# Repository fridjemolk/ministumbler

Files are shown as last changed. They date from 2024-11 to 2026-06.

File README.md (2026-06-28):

# ministumbler, a tiny ESP32 WiFi stumbling tool

This repo contains arduino code, helper python scripts, KiCad and Gerber Files, and hardware information about my ESP32 based WiFi stumbler, designed with low cost, minimal size, and easy of asssembly in mind. It is currently based around the Seeed XIAO/Adafruit QT Py ecosystem.



As of 02/2026, this project exists in 3 different hardware configurations, all of which are based on a GNSS Module, a MicroSD card slot, and a Xiao ESP32-S3:

#### v0.2: A custom PCB backplane supporting each of the modules, plus a [LiPo battery](https://thepihut.com/products/2000mah-3-7v-lipo-battery) charged by the Xiao ESP32-S3's built-in charge circuit, designed to fit into [this case from the Pi Hut](https://thepihut.com/products/small-plastic-project-enclosure-weatherproof-with-clear-top). The KiCad and Gerber files are [available here.](https://github.com/fridjemolk/ministumbler/tree/master/ministumbler_weatherproof_case) 


#### v0.1: A custom flex PCB backplane, supporting each of the modules, designed for stealthy use in the pocket of a bag or inside clothing. The KiCad and Gerber files are [available here.](https://github.com/fridjemolk/ministumbler/tree/master/ministumbler_kicad)


#### v0: A soldered-together stack of all three modules into a very compact rough cube shape. This was the initial prototype and is a little awkward to assemble as it requires deliberately not soldering certain pins for each module. 


All three hardware versions currently [use the same firmware](https://github.com/fridjemolk/ministumbler/blob/master/Ministumbler_WiGLE/Ministumbler_WiGLE.ino), with the same pin configurations, requireing the TX jumper pad to be **CUT** on the SD module and the A1 jumper pad **SOLDERED**. This firmware builds off the firmware created by [lozaning](https://github.com/lozaning) for their [Wifydra Project](https://github.com/lozaning/The_Wifydra), so credit to them for all their hard work in supporting the WiGLE CSV format and handling SD card file creation and management. 

[As of 02/2026, this is the main firmware used for this project](https://github.com/fridjemolk/ministumbler/blob/master/Ministumbler_WiGLE/Ministumbler_WiGLE.ino)

### Required Hardware

#### In the current design version the following three boards are used:

- [Seeed XIAO ESP32S3.](https://wiki.seeedstudio.com/xiao_esp32s3_getting_started/) The S3 variant of the ESP32 has the added benefit of Bluetooth support, and of having a U.FL connector for an external antenna, opening up options for optimising reception. Alternatively, the [Seeed XIAO ESP32C5](https://www.seeedstudio.com/Seeed-Studio-XIAO-ESP32C5-p-6609.html) can be used if 5GHz WiFi support is required, as both boards use the same pinout, however 5GHz is not yet supported by the firmware in this repo.
- [L76K GNSS Module for SeeedStudio XIAO.](https://wiki.seeedstudio.com/get_start_l76k_gnss/) A low-cost, TinyGPS++ compatible GPS module that has proven easy to use and quick to lock. Includes an active GPS antenna, also connected via a U.Fl connector
- [Adafruit microSD Card BFF.](https://learn.adafruit.com/adafruit-microsd-card-bff) A basic microSD card breakout board from adafruit that directly connects an insterted microSD to the SPI pins on the ESP32S3. Since the ESP32S3 has an on-board 3.3v regulator and runs at a 3.3v logic level there is no need for any regulator or level shifter to interface with a microSD card.

The v0 hardware design leads to an issue with the GPS RESET pin being the same as the MOSI (D10) pin of the ESP32, which is used to communicate with the microSD card. For the **v0 configuration ONLY** it is therefore required to ensure that this pin from the ESP32 connects only to the SD board, as the GPS RESET pin is not needed. In fact, the GPS module only requires it's RX, TX, 5V, GND, and 3v3 pins to actually be connected to the ESP32. The 5V pin can also be omitted to disabled the green GPS PPS LED if required.

Optionally, a 3.7V lithium battery can be used to power the device via the BAT +/- pins on the back of the Xiao board, which allow for both powering the Xiao board itself and any devices using it's 3.3v rail (note that no 5v power is available when running on battery), and also for charging the battery over the Xiao's USB-C port - [see this section of the Seeed wiki for more info](https://wiki.seeedstudio.com/xiao_esp32s3_getting_started/#battery-usage). This requires a battery connector being soldered to these pins. In the pictured v0.2 configuration, the pin headers included with the Xiao have been used to solder it to the PCB so as to use the plastic spacer on the headers to allow for the battery wires to reach the BAT +/- pins on the back of the Xiao board. In future this may be updated to use SMD soldering to connect these battery pins to a dedicated battery connector on the board. [This 2000mAh battery](https://thepihut.com/products/2000mah-3-7v-lipo-battery?variant=42143258050755) can power the device for several days in the v0.2 configuration. [This battery connector cable](https://thepihut.com/products/jst-ph-2-pin-cable-male-header-200mm?variant=12364083396670) was used to solder to the Xiao board, and power is applied or removed to the device by simple disconnecting the battery. 

## Software

### This repo, as it currently stands, contains three pieces of software:

- [A fully fledged WiGLE scanning script](https://github.com/fridjemolk/ministumbler/blob/master/Ministumbler_WiGLE/Ministumbler_WiGLE.ino), that scans all wifi channels and creats a WiGLE format CSV that can be uploaded to the WiGLE website.
- [A deprecated, more basic Arduino sketch](https://github.com/fridjemolk/ministumbler/blob/master/GPS_WiFi_XIAO_Serial_CSV/GPS_WiFi_XIAO_Serial_CSV.ino) that interfaces with the GPS module via the ESP32 fork of TinyGPSPlus and uses the Arduino WiFi libray to scan WiFi networks. The sketch will repeatedly generate a line of scanned CSV data with the current GPS location, date, time, and a list of WiFi SSIDs and either output it over USB Serial or save it to a MicroSD card. 
- [A simple python script](https://github.com/fridjemolk/ministumbler/blob/master/csv_write_test.py) that records the data received from the ESP32 over USB Serial and writes it to a CSV file. 

## KiCad Projects

To open these projects in KiCad, clone this repo or download one of the kicad directories and open the `.kicad_pro` file located inside each folder from KiCad's GUI.

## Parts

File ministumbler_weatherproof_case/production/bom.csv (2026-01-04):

Designator | Footprint | Quantity | Value | LCSC Part #
_3 | 54673efd-b35e-49dd-9032-9028876455ca | 1
_2 | 45aaa4f7-1e1c-4795-ac06-623d4f5a70b0 | 1
 |  | 1
ESP32, GPS MODULE, MICRO SD | MOUDLE14P-SMD-2.54-21X17.8MM | 3 | MOUDLE-SEEEDUINO-XIAO-ESP32S3

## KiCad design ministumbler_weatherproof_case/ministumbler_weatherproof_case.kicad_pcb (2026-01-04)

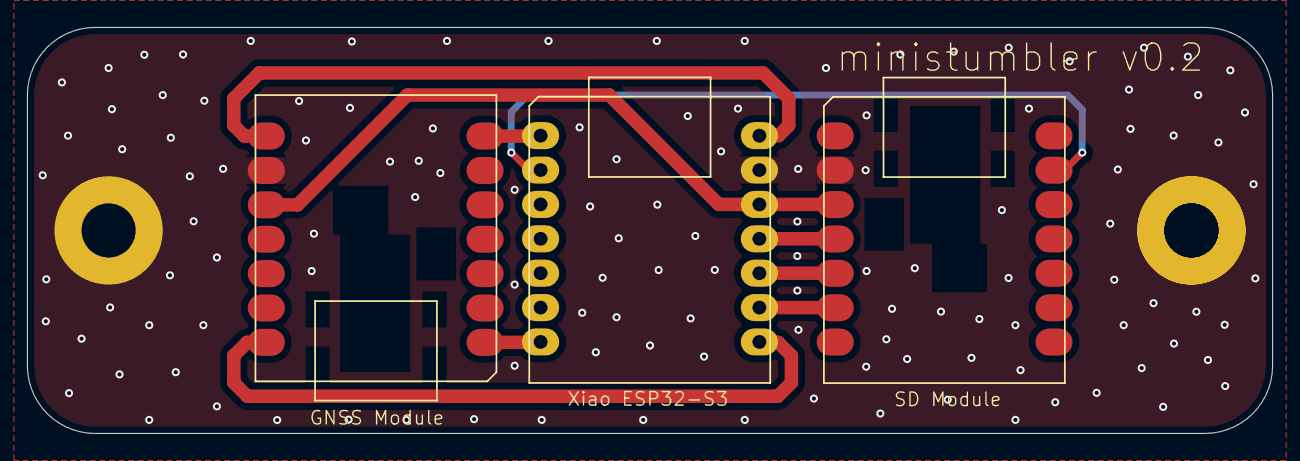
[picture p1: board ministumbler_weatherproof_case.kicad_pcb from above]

Board: 2 copper layers, 92.0 x 30.0 mm, 3 parts (0 on the bottom side), 10 nets.

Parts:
ESP32: MOUDLE-SEEEDUINO-XIAO-ESP32S3; MOUDLE14P-SMD-2.54-21X17.8MM
GPS MODULE: MOUDLE-SEEEDUINO-XIAO-ESP32S3; MOUDLE14P-SMD-2.54-21X17.8MM
MICRO SD: MOUDLE-SEEEDUINO-XIAO-ESP32S3; MOUDLE14P-SMD-2.54-21X17.8MM

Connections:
+3V3: ESP32.12 (3V3), GPS MODULE.10 (PA5_A9_D9_MISO), MICRO SD.3 (PA10_A2_D2)
+5V: ESP32.14 (5V), GPS MODULE.8 (PB09_D7_RX)
GND: ESP32.13 (GND), GPS MODULE.9 (PA7_A8_D8_SCK), MICRO SD.2 (PA4_A1_D1)
GPS_WAKE: ESP32.1 (PA02_A0_D0), GPS MODULE.7 (PB08_A6_TX)
MISO: ESP32.10 (PA5_A9_D9_MISO), MICRO SD.5 (PA8_A4_D4_SDA)
MOSI: ESP32.11 (PA6_A10_D10_MOSI), MICRO SD.4 (PA11_A3_D3)
RX: ESP32.8 (PB09_D7_RX), GPS MODULE.14 (5V)
SCK: ESP32.9 (PA7_A8_D8_SCK), MICRO SD.6 (PA9_A5_D5_SCL)
SD_CS: ESP32.2 (PA4_A1_D1), MICRO SD.13 (GND)
TX: ESP32.7 (PB08_A6_TX), GPS MODULE.1 (PA02_A0_D0)

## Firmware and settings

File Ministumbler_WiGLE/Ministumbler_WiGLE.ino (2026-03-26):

#include <WiFi.h>
#include <SPI.h>
#include <HardwareSerial.h>
#include <TinyGPS++.h>
#include <SD.h>

//TinyGPS++ library documentation is archived here from the developer's now-dead wordpress: https://web.archive.org/web/20250805002451/https://arduiniana.org/libraries/tinygpsplus/
//Quectel L76K GPS Module Protocol Documentation is available here: https://raw.githubusercontent.com/Seeed-Projects/Seeed_L76K-GNSS_for_XIAO/fb74b715224e0ac153c3884e578ee8e024ed8946/docs/Quectel_L76K_GNSS_Protocol_Specification_V1.1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

#define SD_FAT_TYPE 3
#define SD_CS_PIN A1

File csv;
/*
This firmware is inspired by and modified from: 
https://github.com/lozaning/The_Wifydra/blob/main/Dom.ino
https://github.com/lozaning/The_Wifydra/blob/main/Sub.ino

This sketch draws HEAVILY from the above two sources, essentially just modifying them to work as a single script. Credit to https://github.com/lozaning for all of his featured code, modified or unmodified.

https://github.com/dkyazzentwatwa/esp32-gps-wifi-wigle/blob/main/esp32-gps-wifi-wigle.ino
*/
static const int RXPin = D7, TXPin = D6;
static const uint32_t GPSBaud = 9600; // GPS module default baud rate is 9600

//static const bool ENABLE_LED = false;

// The TinyGPSPlus object
TinyGPSPlus gps;

// The serial connection to the GPS device
HardwareSerial GPSSerial(1);

// Counters for WiFi scans and networks found
int scanCount = 0;
int networkCount = 0;
int gpsPrints = 0;


//////////////////////////////////////////////////////////////////////////////////////////////////////////////////////////////
typedef struct struct_message {
  char bssid[64];
  char ssid[32];
  char encryptionType[16];
  int32_t channel;
  int32_t rssi;
} struct_message;

// Constants defined here:
#define LOG_FILE_PREFIX "/gpslog"
#define MAX_LOG_FILES 100
#define LOG_FILE_SUFFIX "csv"
#define LOG_COLUMN_COUNT 11
#define LOG_RATE 500
#define NOTE_DH2 661
const int chipSelect = 10;
File myFile;
char logFileName[13];
int totalNetworks = 0;
unsigned long lastLog = 0;
int integerAltMeters = 0;

//say how many macs we should keep in the buffer to compare for uniqueness
#define mac_history_len 512

const String wigleHeaderFileFormat = "WigleWifi-1.4,appRelease=2.26,model=Ministumbler v0.2,release=0.0.1,device=Ministumbler,display=3fea5e7,board=esp32,brand=Fridje";
char* log_col_names[LOG_COLUMN_COUNT] = {
  "MAC", "SSID", "AuthMode", "FirstSeen", "Channel", "RSSI", "CurrentLatitude", "CurrentLongitude", "AltitudeMeters", "AccuracyMeters", "Type"
};

struct mac_addr {
  unsigned char bytes[6];
};
struct mac_addr mac_history[mac_history_len];
unsigned int mac_history_cursor = 0;

String AP;
String BSSIDchar;
String ENC;
String EncTy;
// Create a struct_message called myData
struct_message myData;

unsigned long lastTime = 0;
unsigned long timerDelay = 200;  // send readings timer

String recentSSID;
String recentSSID1;
String recentSSID2;
//////////////////////////////////////////////////////////////////////////////////////////////////////////////////////////////

void setup()
{
  Serial.begin(115200);
  if(!Serial){
    delay(1);
  } else {
    Serial.println("Serial initialized");
  }
  GPSSerial.begin(GPSBaud, SERIAL_8N1, RXPin, TXPin);
  if(!GPSSerial){
    delay(1);
  } else {
    Serial.println("GPS initialized");
  }
  delay(50);
  Serial.println("Telling L76K which satellite mode to use...");
  Serial.println();
  delay(50);
  GPSSerial.print('$PCAS04,7*1E'); //Tell L76K to use GPS + BeiDou +  GLONASS, which is all the satellite types it supports + QZSS which is always enabled. This will give the best chance at a fix.
  GPSSerial.print('\r\n');
  //Calculate checksum with https://www.meme.au/nmea-checksum.html
  delay(250);
  
  Serial.print("Initializing SD card...");

  if (!SD.begin(SD_CS_PIN)) {
    Serial.println("initialization failed! Check if a card is inserted, and if not, check solder joints on SD module.");
    while(true){
      delay(1);
    }
  } else {
    Serial.print("SD and ");
  }
  Serial.println("GPS initialization done.");

  updateFileName();
  printHeader();

  // initialize digital pin LED_BUILTIN as an output.
  //pinMode(LED_BUILTIN, OUTPUT);
  //digitalWrite(LED_BUILTIN, HIGH);

}

void loop() {
  //Check for GPS lock
  smartDelay(50);
  if (gps.location.isValid() && gps.date.isValid() && gps.time.isValid() && (gps.time.hour() > 0 || gps.time.minute() > 0 || gps.time.second() > 0) && gps.date.year() > 2000){
    print_GPS_date_time();
    scanWiFi();
  } else {
    Serial.println("Waiting for GPS Lock...");
    while (GPSSerial.available())
      gps.encode(GPSSerial.read());
    Serial.print("Current garbage GPS time: ");
    Serial.print(gps.date.year());
    Serial.print(F("-"));
    Serial.print(gps.date.month());
    Serial.print(F("-"));
    Serial.print(gps.date.day());
    Serial.print(F(" "));
    if (gps.time.hour() < 10) Serial.print(F("0"));
    Serial.print(gps.time.hour());
    Serial.print(F(":"));
    if (gps.time.minute() < 10) Serial.print(F("0"));
    Serial.print(gps.time.minute());
    Serial.print(F(":"));
    if (gps.time.second() < 10) Serial.print(F("0"));
    Serial.print(gps.time.second());
    Serial.print(F(":"));
    if (gps.time.centisecond() < 10) Serial.print(F("0"));
    Serial.print(gps.time.centisecond());
    Serial.println(".");
    smartDelay(1000);
  }
}

void print_GPS_date_time(){
    Serial.print("Current GPS time: ");
    Serial.print(gps.date.year());
    Serial.print(F("-"));
    Serial.print(gps.date.month());
    Serial.print(F("-"));
    Serial.print(gps.date.day());
    Serial.print(F(" "));
    if (gps.time.hour() < 10) Serial.print(F("0"));
    Serial.print(gps.time.hour());
    Serial.print(F(":"));
    if (gps.time.minute() < 10) Serial.print(F("0"));
    Serial.print(gps.time.minute());
    Serial.print(F(":"));
    if (gps.time.second() < 10) Serial.print(F("0"));
    Serial.print(gps.time.second());
    Serial.print(F(":"));
    if (gps.time.centisecond() < 10) Serial.print(F("0"));
    Serial.print(gps.time.centisecond());
    Serial.println(".");
}

void scanWiFi(){
  char Buf[50];
  char bufBSSID[64];
  char BufEnc[50];
  if ((millis() - lastTime) > timerDelay) {
    // Set values to send

    //myData.b = random(1,20);
    //myData.c = 1.2;
    //sytanx thus: scanNetworks(bool async, bool show_hidden, bool passive, uint32_t max_ms_per_chan, uint8_t channel)
    int n = WiFi.scanNetworks(false,true,true); //passive scan with hidden networks on all channels and default dwell time
    //int n = WiFi.scanNetworks(); //basic scan, promiscuous 
    if (n == 0) {
      Serial.println("No networks found");
      Serial.println("No networks found");
    } else {
      for (int8_t i = 0; i < n; i++) {
        //delay(10);
        if (seen_mac(WiFi.BSSID(i))) {
          Serial.println("We've already seen it");
          //BSSIDchar = WiFi.BSSID(i);
          //BSSIDchar.toCharArray(bufBSSID, 64);
          //strcpy(myData.bssid, Buf);
          //Serial.println(myData.bssid);
          continue;
        }
        Serial.println("We havent seen it");
        String MacString = WiFi.BSSIDstr(i).c_str();
        //myData.bssid = MacString;
        MacString.toCharArray(bufBSSID, 64);
        strcpy(myData.bssid, bufBSSID);
        Serial.println(myData.bssid);
        //myData.bssid = WiFi.BSSID(i);
        //Serial.print("MyData.bssid: ");

        //Serial.println(myData.bssid);
        String AP = WiFi.SSID(i);
        AP.toCharArray(Buf, 50);
        strcpy(myData.ssid, Buf);
        Serial.print("SSID: ");
        Serial.println(myData.ssid);
        //String ENC = security_int_to_string(WiFi.encryptionType(i));

        //ENC.toCharArray(BufEnc, 32);
        //strcpy(myData.encryptionType, BufEnc);
        //myData.encryptionType = authtype;
        switch (WiFi.encryptionType(i)) {
          case WIFI_AUTH_OPEN:
            EncTy = "Open";
            break;
          case WIFI_AUTH_WEP:
            EncTy = "WEP";
            break;
          case WIFI_AUTH_WPA_PSK:
            EncTy = "WPA PSK";
            break;
          case WIFI_AUTH_WPA2_PSK:
            EncTy = "WPA2 PSK";
            break;
          case WIFI_AUTH_WPA_WPA2_PSK:
            EncTy = "WPA/WPA2 PSK";
            break;
          case WIFI_AUTH_WPA2_ENTERPRISE:
            EncTy = "WPA2 Enterprise";
            break;
          default:
            EncTy = "Unknown";
            break;
        }
        EncTy.toCharArray(BufEnc, 16);
        strcpy(myData.encryptionType, BufEnc);
        Serial.print("Encryption: ");
        Serial.println(myData.encryptionType);

        myData.channel = WiFi.channel(i);
        myData.rssi = WiFi.RSSI(i);
        save_mac(WiFi.BSSID(i));
        writeToCSV((uint8_t*)&myData, sizeof(myData));
        //digitalWrite(2, LOW);
        delay(200);
        //digitalWrite(2, HIGH);
      }
      lastTime = millis();
    }
  }
}

void save_mac(unsigned char* mac) {
  //Save a MAC address into the recently seen array.
  if (mac_history_cursor >= mac_history_len) {
    mac_history_cursor = 0;
  }
  struct mac_addr tmp;
  for (int x = 0; x < 6; x++) {
    tmp.bytes[x] = mac[x];
  }

  mac_history[mac_history_cursor] = tmp;
  mac_history_cursor++;
  Serial.print("Mac len ");
  Serial.println(mac_history_cursor);
}

bool mac_cmp(struct mac_addr addr1, struct mac_addr addr2) {
  //Return true if 2 mac_addr structs are equal.
  for (int y = 0; y < 6; y++) {
    if (addr1.bytes[y] != addr2.bytes[y]) {
      return false;
    }
  }
  return true;
}

bool seen_mac(unsigned char* mac) {
  //Return true if this MAC address is in the recently seen array.

  struct mac_addr tmp;
  for (int x = 0; x < 6; x++) {
    tmp.bytes[x] = mac[x];
  }

  for (int x = 0; x < mac_history_len; x++) {
    if (mac_cmp(tmp, mac_history[x])) {
      return true;
    }
  }
  return false;
}

void print_mac(struct mac_addr mac) {
  //Print a mac_addr struct nicely.
  for (int x = 0; x < 6; x++) {
    Serial.print(mac.bytes[x], HEX);
    Serial.print(":");
  }
}

String security_int_to_string(int security_type) {
  //Provide a security type int from WiFi.encryptionType(i) to convert it to a String which Wigle CSV expects.
  String authtype = "";
  switch (security_type) {
    case WIFI_AUTH_OPEN:
      authtype = "[OPEN]";
      break;

    case WIFI_AUTH_WEP:
      authtype = "[WEP]";
      break;

    case WIFI_AUTH_WPA_PSK:
      authtype = "[WPA_PSK]";
      break;

    case WIFI_AUTH_WPA2_PSK:
      authtype = "[WPA2_PSK]";
      break;

    case WIFI_AUTH_WPA_WPA2_PSK:
      authtype = "[WPA_WPA2_PSK]";
      break;

    case WIFI_AUTH_WPA2_ENTERPRISE:
      authtype = "[WPA2]";
      break;

    //Requires at least v2.0.0 of https://github.com/espressif/arduino-esp32/
    case WIFI_AUTH_WPA3_PSK:
      authtype = "[WPA3_PSK]";
      break;

    case WIFI_AUTH_WPA2_WPA3_PSK:
      authtype = "[WPA2_WPA3_PSK]";

    default:
      authtype = "";
  }

  return authtype;
}

void updateFileName() {
  int i = 0;
  for (; i < MAX_LOG_FILES; i++) {
    memset(logFileName, 0, strlen(logFileName));
    sprintf(logFileName, "%s%d.%s", LOG_FILE_PREFIX, i, LOG_FILE_SUFFIX);
    if (!SD.exists(logFileName)) {
      Serial.println("we picked a new file name");
      Serial.println(logFileName);
      break;
    } else {
      Serial.print(logFileName);
      Serial.println(" exists");
    }
  }
  Serial.println("File name: ");
  Serial.println(logFileName);
}

void printHeader() {
  File logFile = SD.open(logFileName, FILE_WRITE);
  if (logFile) {
    int i = 0;
    logFile.println(wigleHeaderFileFormat);  // comment out to disable Wigle header
    for (; i < LOG_COLUMN_COUNT; i++) {
      logFile.print(log_col_names[i]);
      if (i < LOG_COLUMN_COUNT - 1)
        logFile.print(',');
      else
        logFile.println();
    }
    logFile.close();
  }
}

static void smartDelay(unsigned long ms)  // custom version of delay() ensures that the gps object is being "fed".
{
  unsigned long start = millis();
  do {
    while (GPSSerial.available())
      gps.encode(GPSSerial.read());
  } while (millis() - start < ms);
}

//Function that will be executed when scan is complete
void writeToCSV(const uint8_t* incomingData, int len) {
  File logFile = SD.open(logFileName, FILE_APPEND);
  memcpy(&myData, incomingData, sizeof(myData));
  char buffer[10];
  Serial.print("Bytes received: ");
  Serial.println(len);
  Serial.print("Mac: ");
  Serial.println(myData.bssid);
  logFile.print(myData.bssid);
  logFile.print(",");
  Serial.print("SSID: ");
  Serial.println(myData.ssid);
  String SSIDString = myData.ssid;
  if(SSIDString.indexOf(",") > 0) {
    SSIDString = "\""+SSIDString+"\"";
  }
  logFile.print(SSIDString);
  logFile.print(",");
  Serial.print("Encryption: ");
  Serial.println(myData.encryptionType);
  logFile.print(myData.encryptionType);
  logFile.print(",");
  Serial.print("First seen: ");

  //date
  Serial.println(gps.date.year());
  logFile.print(gps.date.year());
  logFile.print("-");

  snprintf(buffer , sizeof buffer, "%02d", gps.date.month());
  Serial.print(buffer);
  logFile.print(buffer);
  logFile.print("-");

  snprintf(buffer , sizeof buffer, "%02d", gps.date.day());
  Serial.print(buffer);
  logFile.print(buffer);

  logFile.print(" ");

  //time
  snprintf(buffer , sizeof buffer, "%02d", gps.time.hour());
  Serial.print(buffer);
  logFile.print(buffer);
  logFile.print(":");

  snprintf(buffer , sizeof buffer, "%02d", gps.time.minute());
  Serial.print(buffer);
  logFile.print(buffer);
  logFile.print(":");

  snprintf(buffer , sizeof buffer, "%02d", gps.time.second());
  Serial.print(buffer);
  logFile.print(buffer);

  logFile.print(",");
  Serial.print("Channel: ");
  Serial.println(myData.channel);
  logFile.print(myData.channel);
  logFile.print(",");
  Serial.print("RSSI:  ");
  Serial.println(myData.rssi);
  logFile.print(myData.rssi);
  logFile.print(",");
  Serial.print("Lat: ");
  Serial.println(gps.location.lat(), 8);
  logFile.print(gps.location.lat(), 8);
  logFile.print(",");
  Serial.print("Lon: ");
  Serial.println(gps.location.lng(), 8);
  logFile.print(gps.location.lng(), 8);
  logFile.print(",");
  Serial.print("Altitude: ");
  integerAltMeters = int(round(gps.altitude.meters()));
  Serial.println(integerAltMeters);
  logFile.print(integerAltMeters);
  logFile.print(",");
  Serial.print("HDOP: ");
  Serial.println(gps.hdop.value());
  // Convert HDOP to accuracy in meters (HDOP*100 / 10 = rough accuracy)
  logFile.print(gps.hdop.value() / 10.0, 1);
  logFile.print(",");
  Serial.print("BiD: ");
  logFile.print("WIFI");
  logFile.println();
  logFile.close();
  recentSSID2 = recentSSID1;
  recentSSID1 = recentSSID;
  recentSSID = myData.ssid;
  Serial.println();
  totalNetworks +=1;
  Serial.print("Total Networks: ");
  Serial.println(totalNetworks);

  Serial.println();
  Serial.println();
  Serial.println();
}

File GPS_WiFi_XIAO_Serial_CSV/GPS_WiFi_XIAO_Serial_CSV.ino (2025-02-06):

#include <WiFi.h>
//#include <WiFiAP.h>
//#include <WiFiClient.h>
//#include <WiFiGeneric.h>
//#include <WiFiMulti.h>
//#include <WiFiScan.h>
//#include <WiFiServer.h>
//#include <WiFiSTA.h>
//#include <WiFiType.h>
//#include <WiFiUdp.h>
#include <TinyGPSPlus.h>
#include <SoftwareSerial.h>
#include <SPI.h>
#include "SdFat.h"
SdFat SD;

#define SD_FAT_TYPE 3
#define SD_CS_PIN A1

File csv;
/*
Includes some code inspired by and modified from: https://github.com/dkyazzentwatwa/esp32-gps-wifi-wigle/blob/main/esp32-gps-wifi-wigle.ino
*/
static const int RXPin = D7, TXPin = D6;
static const uint32_t GPSBaud = 9600;

// The TinyGPSPlus object
TinyGPSPlus gps;

// The serial connection to the GPS device
SoftwareSerial ss(RXPin, TXPin);

// Counters for WiFi scans and networks found
int scanCount = 0;
int networkCount = 0;
int gpsPrints = 0;

void setup()
{
  Serial.begin(115200);
  ss.begin(GPSBaud);

  Serial.print("Initializing SD card...");

  if (!SD.begin(SD_CS_PIN)) {
    Serial.println("initialization failed!");
    return;
  }
  Serial.println("initialization done.");

  //open the file
  csv = SD.open("ministumbler.csv", FILE_WRITE);

  // initialize digital pin LED_BUILTIN as an output.
  pinMode(LED_BUILTIN, OUTPUT);
  digitalWrite(LED_BUILTIN, LOW);

  //Serial.println(F("DeviceExample.ino"));
  //Serial.println(F("A simple demonstration of TinyGPSPlus with an attached GPS module"));
  //Serial.print(F("Testing TinyGPSPlus library v. ")); Serial.println(TinyGPSPlus::libraryVersion());
  //Serial.println(F("by Mikal Hart"));
  //Serial.println();

  Serial.print("Latitude");
  Serial.print(F(","));
  Serial.print("Longitude");
  Serial.print(F(","));
  Serial.print("Month");
  Serial.print(F(","));
  Serial.print("Day");
  Serial.print(F(","));
  Serial.print("Year");
  Serial.print(F(","));
  Serial.print("Hour");
  Serial.print(F(","));
  Serial.print("Minute");
  Serial.print(F(","));
  Serial.print("Second");
  Serial.print(F(","));
  Serial.print("Centisecond");
  Serial.print(F(","));
  Serial.print("Scan Count");
  Serial.print(F(","));
  Serial.print("Network Count");
  Serial.print(F(","));
  Serial.print("SSID");
  Serial.print(F(","));
  Serial.print("RSSI");
  Serial.print(F(","));
  Serial.print("MAC");
  Serial.print(F(","));
  Serial.println("");

  if(csv){
    csv.print("Latitude");
    csv.print(F(","));
    csv.print("Longitude");
    csv.print(F(","));
    csv.print("Month");
    csv.print(F(","));
    csv.print("Day");
    csv.print(F(","));
    csv.print("Year");
    csv.print(F(","));
    csv.print("Hour");
    csv.print(F(","));
    csv.print("Minute");
    csv.print(F(","));
    csv.print("Second");
    csv.print(F(","));
    csv.print("Centisecond");
    csv.print(F(","));
    csv.print("Scan Count");
    csv.print(F(","));
    csv.print("Network Count");
    csv.print(F(","));
    csv.print("SSID");
    csv.print(F(","));
    csv.print("RSSI");
    csv.print(F(","));
    csv.print("MAC");
    csv.print(F(","));
    csv.println("");
    csv.flush();
  }

}

void loop(){
  // This sketch displays information every time a new sentence is correctly encoded.
  while (ss.available() > 0){
    if (gps.encode(ss.read()) && gps.location.isValid() && gps.date.isValid() && gps.time.isValid()){
      scanWiFiNetworks();
      csv.flush();
      digitalWrite(LED_BUILTIN, HIGH);
    } else {
      digitalWrite(LED_BUILTIN, LOW);
    }
  }
}


void printGPS(){
  if (gps.location.isValid())
  {
    Serial.print(gps.location.lat(), 6);
    Serial.print(F(","));
    Serial.print(gps.location.lng(), 6);
    Serial.print(F(","));
  }

  if (gps.date.isValid())
  {
    Serial.print(gps.date.month());
    Serial.print(F(","));
    Serial.print(gps.date.day());
    Serial.print(F(","));
    Serial.print(gps.date.year());
    Serial.print(F(","));
  }
  
  if (gps.time.isValid())
  {
    if (gps.time.hour() < 10) Serial.print(F("0"));
    Serial.print(gps.time.hour());
    Serial.print(F(","));
    if (gps.time.minute() < 10) Serial.print(F("0"));
    Serial.print(gps.time.minute());
    Serial.print(F(","));
    if (gps.time.second() < 10) Serial.print(F("0"));
    Serial.print(gps.time.second());
    Serial.print(F(","));
    if (gps.time.centisecond() < 10) Serial.print(F("0"));
    Serial.print(gps.time.centisecond());
  }
  Serial.print(F(","));
}

void writeGPS(){
  if (gps.location.isValid())
  {
    csv.print(gps.location.lat(), 6);
    csv.print(F(","));
    csv.print(gps.location.lng(), 6);
    csv.print(F(","));
  }

  if (gps.date.isValid())
  {
    csv.print(gps.date.month());
    csv.print(F(","));
    csv.print(gps.date.day());
    csv.print(F(","));
    csv.print(gps.date.year());
    csv.print(F(","));
  }
  
  if (gps.time.isValid())
  {
    if (gps.time.hour() < 10) Serial.print(F("0"));
    csv.print(gps.time.hour());
    csv.print(F(","));
    if (gps.time.minute() < 10) Serial.print(F("0"));
    csv.print(gps.time.minute());
    csv.print(F(","));
    if (gps.time.second() < 10) Serial.print(F("0"));
    csv.print(gps.time.second());
    csv.print(F(","));
    if (gps.time.centisecond() < 10) Serial.print(F("0"));
    csv.print(gps.time.centisecond());
  }
  csv.print(F(","));
}

// Scan for WiFi networks and store results in the CSV file
//Function modified from: https://github.com/dkyazzentwatwa/esp32-gps-wifi-wigle/blob/main/esp32-gps-wifi-wigle.ino
void scanWiFiNetworks() {
  if(csv){
    writeGPS();
  }
  printGPS();
  networkCount = WiFi.scanNetworks(); // Scan for WiFi networks
  scanCount++; // Increment scan count

  if(csv){
    // Print networks to SD card CSV file
    csv.print(scanCount);
    csv.print(F(","));
    csv.print(networkCount);
    csv.print(F(","));
    for (int i = 0; i < networkCount; ++i) {
      csv.print(WiFi.SSID(i));
      csv.print(F(","));
      csv.print(WiFi.RSSI(i));
      csv.print(F(","));
      //csv.print(WiFi.macAddress());
    }
    csv.println("");
  }

  // Print networks to serial monitor
  Serial.print(scanCount);
  Serial.print(F(","));
  Serial.print(networkCount);
  Serial.print(F(","));
  for (int i = 0; i < networkCount; ++i) {
    Serial.print(WiFi.SSID(i));
    Serial.print(F(","));
    Serial.print(WiFi.RSSI(i));
    Serial.print(F(","));
    //Serial.print(WiFi.macAddress());
  }
  Serial.println("");
}

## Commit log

2024-10-26 Added arduino CSV serial sketch
2024-10-28 Added hardware and software details to README.md
    Added details of the first hardware and software versions of this project.
    TODO: Add an explanation of how to assemble the project
2024-11-02 Added intial flex pcb design
    [warwalker.kicad_pcb, warwalker.kicad_sch]
2024-11-02 Added KiCad info to README.md
2024-11-02 Added KiCad project
    [ministumbler.kicad_pcb, ministumbler.kicad_sch]
2024-11-02 Updated README.md with KiCad info
2026-01-04 added kicad and gerber files
    added kicad and gerber files for the deaddrop weatherproof ministumbler variant
    [bom.csv, designators.csv, ministumbler_weatherproof_case.kicad_pcb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]
2026-02-06 Added WiGLE Arduino Sketch
2026-03-26 Switch WiFi scan to passive mode, updated CSV header
